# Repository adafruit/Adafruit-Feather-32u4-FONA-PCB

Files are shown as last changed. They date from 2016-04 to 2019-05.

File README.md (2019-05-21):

## Adafruit Feather 32u4 FONA PCB
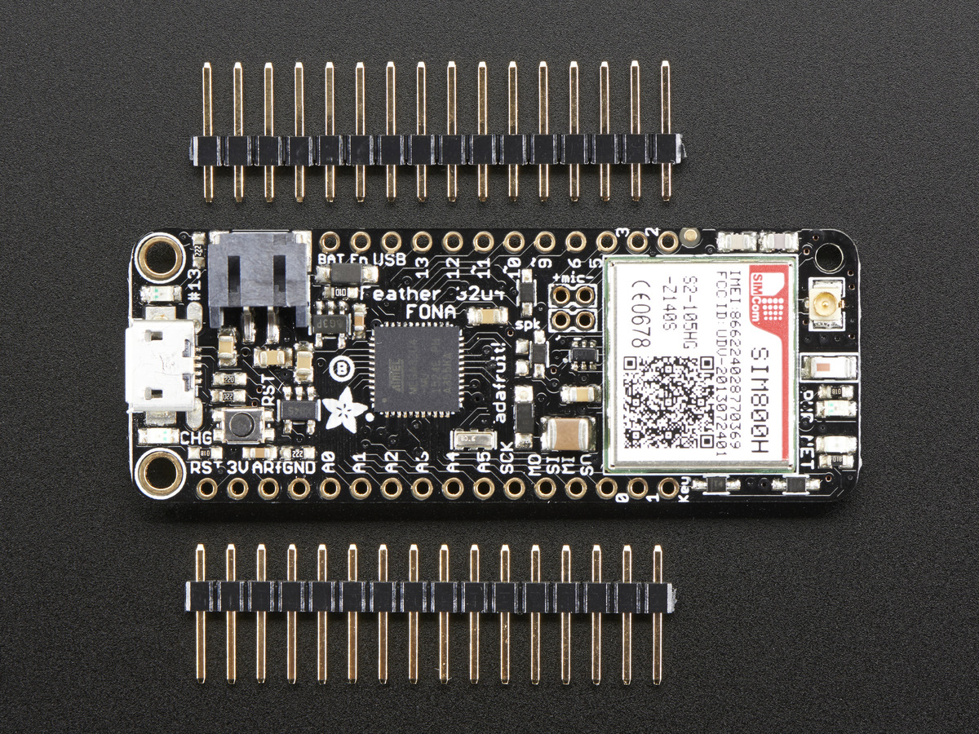
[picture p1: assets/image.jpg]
<a href="http://www.adafruit.com/products/3027"><br/>
Click here to purchase one from the Adafruit shop</a>

This is the Adafruit Feather 32u4 FONA - our take on an 'all-in-one' Arduino-compatible + audio/sms/data capable cellular with built in USB and battery charging. Its an Adafruit Feather 32u4 with a FONA800 module, ready to rock! We have other boards and accessories in the Feather family, check'em out here.

At the Feather 32u4's heart is at ATmega32u4 clocked at 8 MHz and at 3.3V logic, a chip setup we've had tons of experience with as it's the same as the Flora. This chip has 32K of flash and 2K of RAM, with built in USB so not only does it have a USB-to-Serial program & debug capability built in with no need for an FTDI-like chip, it can also act like a mouse, keyboard, USB MIDI device, etc.

Since you'll be taking this on the road, we added a connector for any of our 3.7V Lithium polymer batteries and built in battery charging. A 500mAh+ Lipoly battery is required for use, it keeps the cellular module happy during the high current spikes. Plug the Feather into microUSB to charge at 500mA.

PCB files for Adafruit Feather 32u4 FONA. The format is EagleCAD schematic and board layout
- https://www.adafruit.com/product/3027

### License

Adafruit invests time and resources providing this open source design, please support Adafruit and open-source hardware by purchasing products from [Adafruit](https://www.adafruit.com)!

All text above must be included in any redistribution

Designed by Limor Fried/Ladyada for Adafruit Industries.
Creative Commons Attribution/Share-Alike, all text above must be included in any redistribution. 
See license.txt for additional information.

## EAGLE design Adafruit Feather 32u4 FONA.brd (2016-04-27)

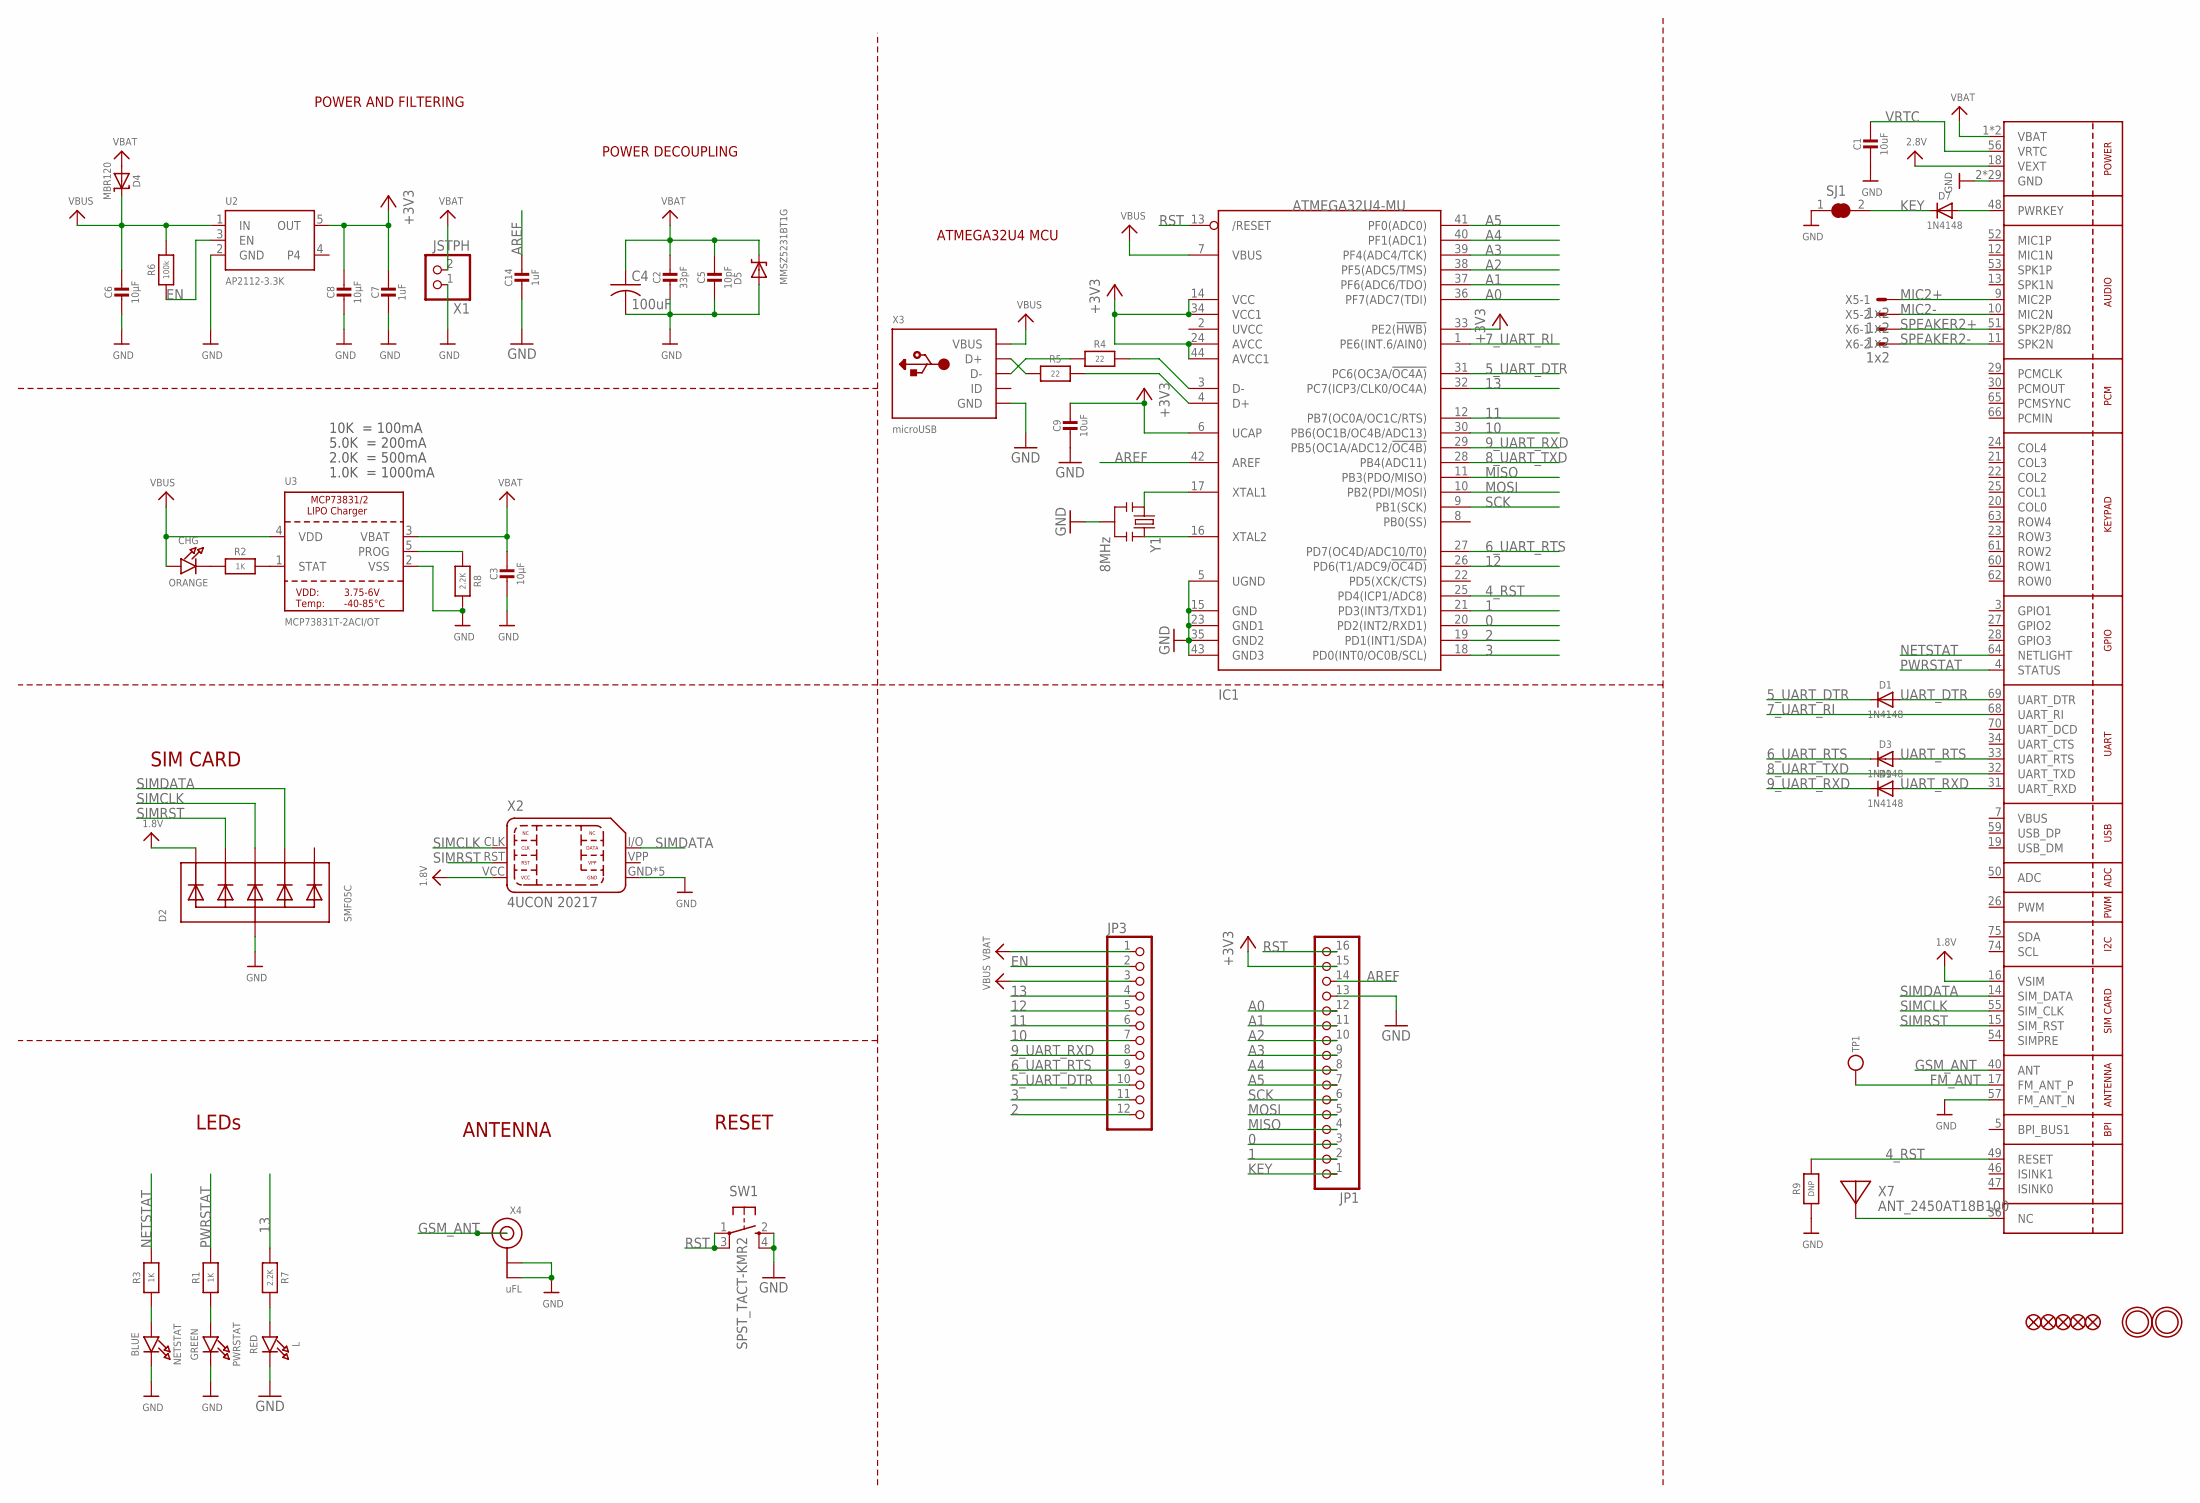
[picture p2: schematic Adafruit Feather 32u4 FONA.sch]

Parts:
C1, C9: 10uF; _0805MP
C2: 33pF; 0805-NO
C3, C6, C8: 10µF; 0805-NO
C4: 100uF; C1210
C5: 10pF; 0805-NO
C7, C14: 1uF; 0603-NO
CHG: ORANGE; CHIPLED_0805_NOOUTLINE
D1, D3, D7, D9: 1N4148; SOD-323
D2: SMF05C; SOT363
D4: MBR120; SOD-123
D5: MMSZ5231BT1G; SOD-123
IC1: ATMEGA32U4-MU; TQFN44_7MM
JP1: HEADER-1X16ROUND; 1X16_ROUND
JP3: HEADER-1X12; 1X12_ROUND
L: RED; CHIPLED_0805_NOOUTLINE
NETSTAT: BLUE; CHIPLED_0805_NOOUTLINE
PWRSTAT: GREEN; CHIPLED_0805_NOOUTLINE
R1, R2, R3: 1K; 0603-NO
R4, R5: 22; 0603-NO
R6: 100k; 0603-NO
R7, R8: 2.2K; 0603-NO
R9: DNP; 0603-NO
SJ1: SOLDERJUMPER_CLOSED; SOLDERJUMPER_CLOSEDWIRE
SW1: SPST_TACT-KMR2; KMR2
TP1: TESTPOINTROUND1.5MM; TESTPOINT_ROUND_1.5MM
U1: SIM800H/L; SIM800L
U2: AP2112-3.3K; SOT23-5
U3: MCP73831T-2ACI/OT; SOT23-5
U$18, U$23, U$34, U$35, U$42: FIDUCIAL""; FIDUCIAL_1MM
U$31, U$32: MOUNTINGHOLE2.5; MOUNTINGHOLE_2.5_PLATED
X1: JSTPH; JSTPH2
X2: 4UCON 20217; 4UCONN_20217
X3: microUSB; 4UCONN_20329_V2
X4: uFL; U.FL
X5, X6: 1x2; 87758-0216
X7: ANT_2450AT18B100
Y1: 8MHz; RESONATOR-SMD

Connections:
0: IC1.20 (PD2(INT2/RXD1)), JP1.3
1: IC1.21 (PD3(INT3/TXD1)), JP1.2
1.8V: D2.1 (C1), U1.16 (VSIM), X2.VCC
2: IC1.19 (PD1(INT1/SDA)), JP3.12
2.8V: U1.18 (VEXT)
3: IC1.18 (PD0(INT0/OC0B/SCL)), JP3.11
4_RST: IC1.25 (PD4(ICP1/ADC8)), R9.2, U1.49 (RESET)
5_UART_DTR: D1.C, IC1.31 (PC6(OC3A/!OC4A)), JP3.10
6_UART_RTS: D3.C, IC1.27 (PD7(OC4D/ADC10/T0)), JP3.9
7_UART_RI: IC1.1 (PE6(INT.6/AIN0)), U1.68 (UART_RI)
8_UART_TXD: IC1.28 (PB4(ADC11)), U1.32 (UART_TXD)
9_UART_RXD: D9.C, IC1.29 (PB5(OC1A/ADC12/!OC4B)), JP3.8
10: IC1.30 (PB6(OC1B/OC4B/ADC13)), JP3.7
11: IC1.12 (PB7(OC0A/OC1C/RTS)), JP3.6
12: IC1.26 (PD6(T1/ADC9/!OC4D)), JP3.5
13: IC1.32 (PC7(ICP3/CLK0/OC4A)), JP3.4, R7.1
+3V3: C7.1, C8.1, C9.1, IC1.6 (UCAP), IC1.14 (VCC), IC1.24 (AVCC), IC1.33 (PE2(!HWB)), IC1.34 (VCC1), IC1.44 (AVCC1), JP1.15, U2.5 (OUT)
A0: IC1.36 (PF7(ADC7(TDI)), JP1.12
A1: IC1.37 (PF6(ADC6/TDO)), JP1.11
A2: IC1.38 (PF5(ADC5/TMS)), JP1.10
A3: IC1.39 (PF4(ADC4/TCK)), JP1.9
A4: IC1.40 (PF1(ADC1)), JP1.8
A5: IC1.41 (PF0(ADC0)), JP1.7
AREF: C14.1, IC1.42 (AREF), JP1.14
D+: IC1.4 (D+), R5.2
D-: IC1.3 (D-), R4.2
EN: JP3.2, R6.1, U2.3 (EN)
FM_ANT: TP1.P$1, U1.17 (FM_ANT_P)
GND: C1.2, C2.2, C3.2, C4.2, C5.2, C6.2, C7.2, C8.2, C9.2, C14.2, D2.2 (A), D5.A, IC1.5 (UGND), IC1.15 (GND), IC1.23 (GND1), IC1.35 (GND2), IC1.43 (GND3), JP1.13, L.C, NETSTAT.C, PWRSTAT.C, R8.2, R9.1, SJ1.1, SW1.2 (S), SW1.4 (S1), U1.2 (GND), U1.6 (GND), U1.8 (GND), U1.35 (GND), U1.37 (GND), U1.38 (GND), U1.39 (GND), U1.41 (GND), U1.43 (GND), U1.44 (GND), U1.45 (GND), U1.57 (FM_ANT_N), U1.58 (GND), U1.67 (GND), U1.71 (GND), U1.72 (GND), U1.73 (GND), U1.76 (GND), U1.77 (GND), U1.78 (GND), U1.79 (GND), U1.80 (GND), U1.81 (GND), U1.82 (GND), U1.83 (GND), U1.84 (GND), U1.85 (GND), U1.86 (GND), U1.87 (GND), U1.88 (GND), U2.2 (GND), U3.2 (VSS), X1.1, X2.GND, X2.GND@1 (GND), X2.GND@2 (GND), X2.GND@3 (GND), X2.GND@4 (GND), X3.BASE@1 (GND), X3.BASE@2 (GND), X3.GND, X3.SPRT@1 (GND), X3.SPRT@2 (GND), X3.SPRT@3 (GND), X3.SPRT@4 (GND), X4.1 (GND), X4.2 (GND), Y1.2
GSM_ANT: U1.40 (ANT), X4.3 (SIGNAL)
KEY: D7.C, JP1.1, SJ1.2
MIC2+: U1.9 (MIC2P), X5.1
MIC2-: U1.10 (MIC2N), X5.2
MISO: IC1.11 (PB3(PDO/MISO)), JP1.4
MOSI: IC1.10 (PB2(PDI/MOSI)), JP1.5
unnamed: CHG.C, R2.1
unnamed: L.A, R7.2
unnamed: R2.2, U3.1 (STAT)
unnamed: R8.1, U3.5 (PROG)
unnamed: PWRSTAT.A, R1.1
unnamed: U1.36 (NC), X7.FP
unnamed: D7.A, U1.48 (PWRKEY)
unnamed: NETSTAT.A, R3.1
unnamed: IC1.16 (XTAL2), Y1.3
unnamed: IC1.17 (XTAL1), Y1.1
unnamed: R5.1, X3.D+
unnamed: R4.1, X3.D-
NETSTAT: R3.2, U1.64 (NETLIGHT)
PWRSTAT: R1.2, U1.4 (STATUS)
RST: IC1.13 (/RESET), JP1.16, SW1.1, SW1.3 (P1)
SCK: IC1.9 (PB1(SCK)), JP1.6
SIMCLK: D2.4 (C3), U1.55 (SIM_CLK), X2.CLK
SIMDATA: D2.5 (C4), U1.14 (SIM_DATA), X2.I/O (DATA)
SIMRST: D2.3 (C2), U1.15 (SIM_RST), X2.RST
SPEAKER2+: U1.51 (SPK2P/8Ω), X6.1
SPEAKER2-: U1.11 (SPK2N), X6.2
UART_DTR: D1.A, U1.69 (UART_DTR)
UART_RTS: D3.A, U1.33 (UART_RTS)
UART_RXD: D9.A, U1.31 (UART_RXD)
VBAT: C2.1, C3.1, C4.1, C5.1, D4.A, D5.C, JP3.1, U1.1 (VBAT), U1.42 (VBAT), U3.3 (VBAT), X1.2
VBUS: C6.1, CHG.A, D4.C, IC1.7 (VBUS), JP3.3, R6.2, U1.7 (VBUS), U2.1 (IN), U3.4 (VDD), X3.VBUS
VRTC: C1.1, U1.56 (VRTC)

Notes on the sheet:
POWER AND FILTERING
RESET
ATMEGA32U4 MCU
10K = 100mA
5.0K = 200mA
2.0K = 500mA
1.0K = 1000mA
ANTENNA
SIM CARD
POWER DECOUPLING
LEDs

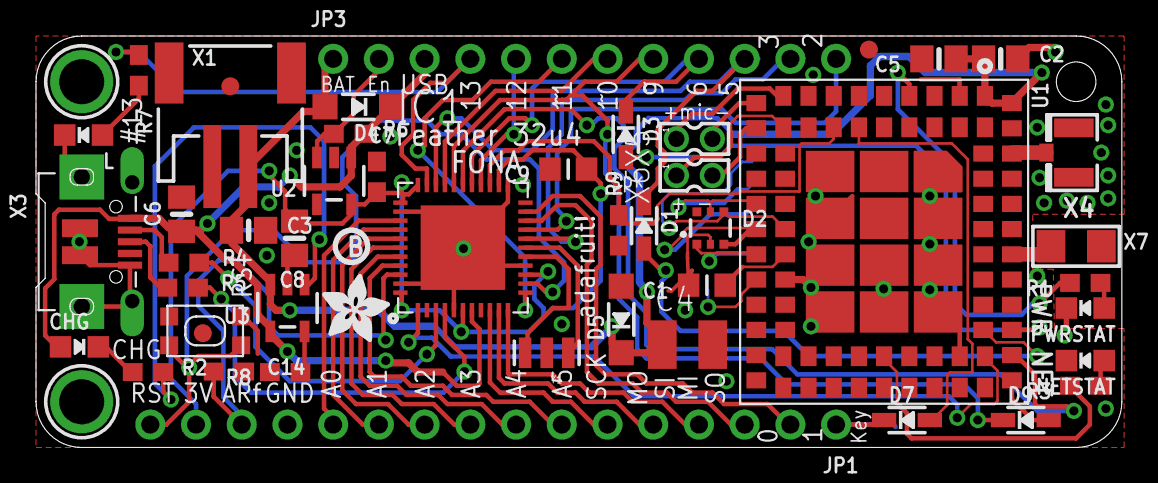
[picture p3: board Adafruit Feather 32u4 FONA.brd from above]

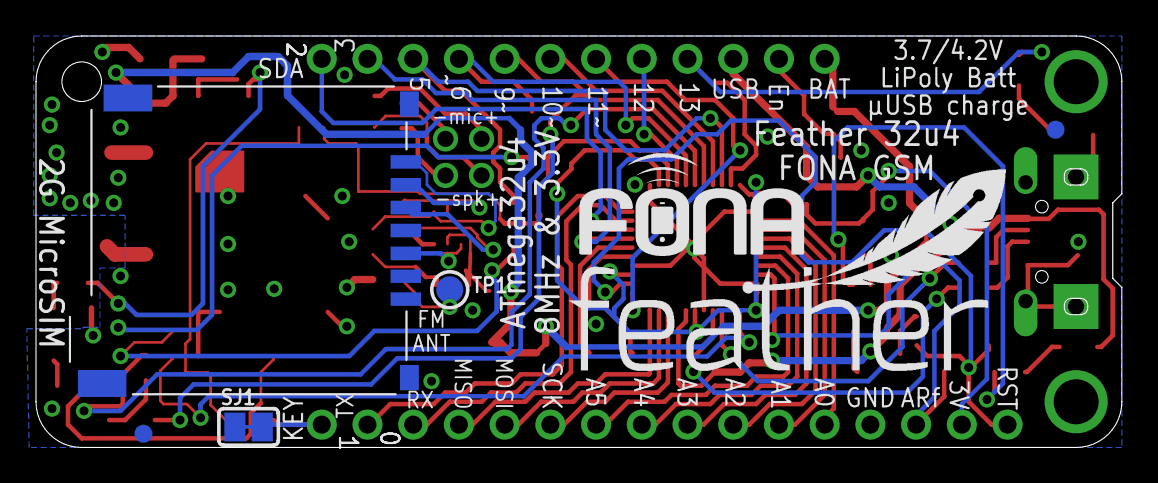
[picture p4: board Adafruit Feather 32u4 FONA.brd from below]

Board: 2 copper layers, 60.3 x 22.9 mm, 58 parts (7 on the bottom side), 61 nets.

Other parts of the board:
U$7: ADAFRUIT_3.5MM
U$25: FEATHERLOGO
U$43: FONA_LOGO_SMALL
U$44: PCBFEAT-REV-040

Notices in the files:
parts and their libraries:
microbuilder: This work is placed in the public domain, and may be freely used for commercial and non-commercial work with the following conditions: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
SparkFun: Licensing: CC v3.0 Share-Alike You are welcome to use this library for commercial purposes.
